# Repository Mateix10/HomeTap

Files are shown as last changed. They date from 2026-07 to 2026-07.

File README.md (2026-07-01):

# HomeTap
A haptic button that connects to HomeAssistant

I always wanted a premium button that is simple and only does a few actions - Toggle the lights on and off and change the color of the LEDs in my room.

# Design
For the design, I used a very simple and minimalistic look, while looking sleek and modern.

It features a LED ring made out of 24 RGB LEDs that light up when the user's finger gets close to the button. This design is inspired from the prototype steam box.

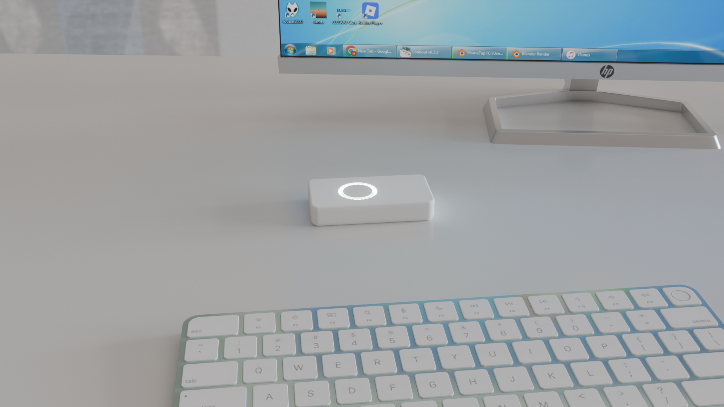
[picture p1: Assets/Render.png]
Render


# Schematic and PCB
This device features a custom pcb. I used [kicad](https://www.kicad.org/).

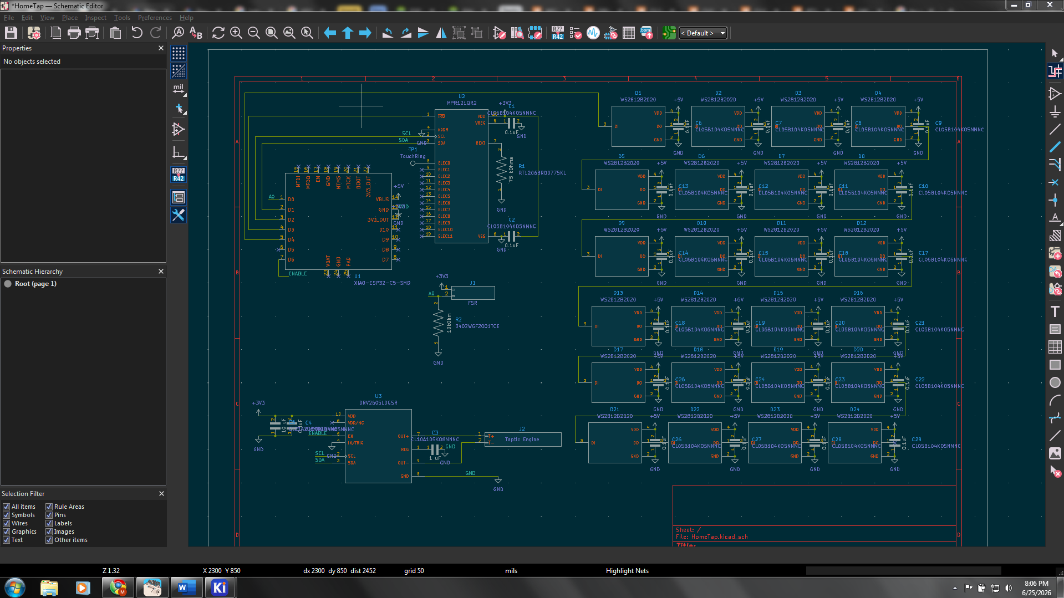
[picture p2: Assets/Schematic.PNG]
Schematic


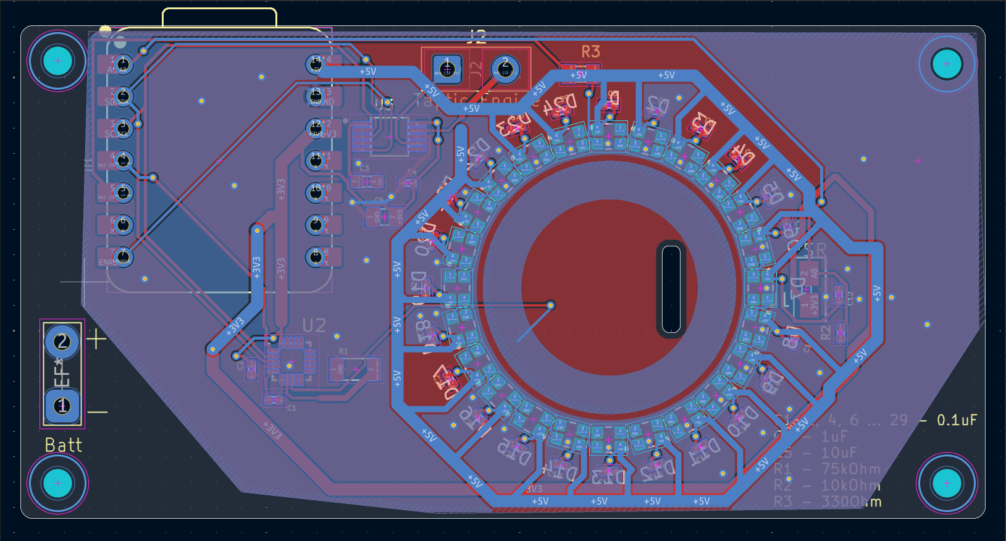
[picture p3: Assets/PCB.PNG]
PCB


# Credits
This project uses:

[KICAD](https://www.kicad.org/)

[Blender](https://www.blender.org/) - For renders

[HackClub Fallout](fallout.hackclub.com) - Founding

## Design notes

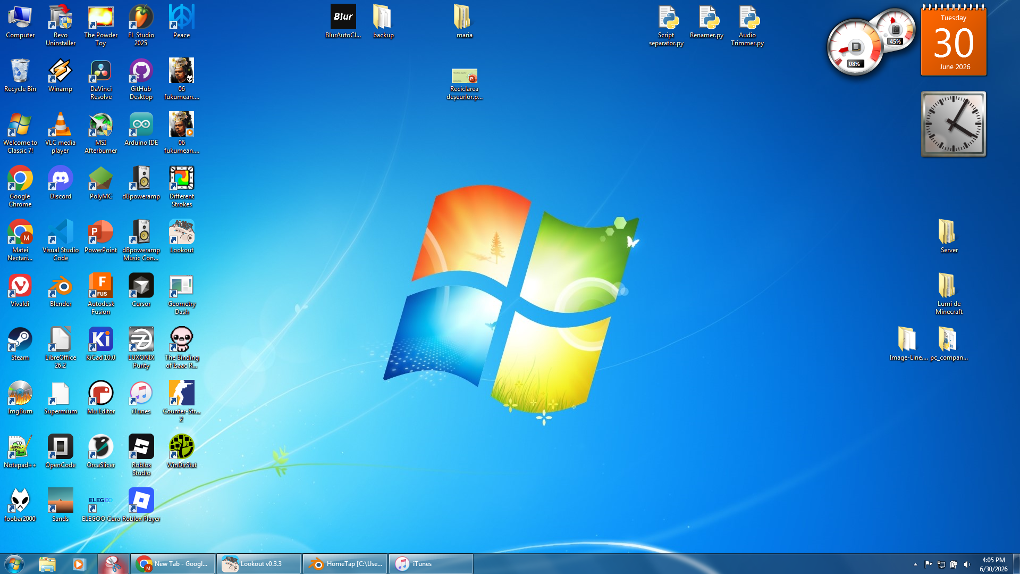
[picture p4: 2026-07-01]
CAD/Blender/assets/models/office-monitor-h_9a68db67-679b-459e-a5c5-594c98094943/Screen.PNG

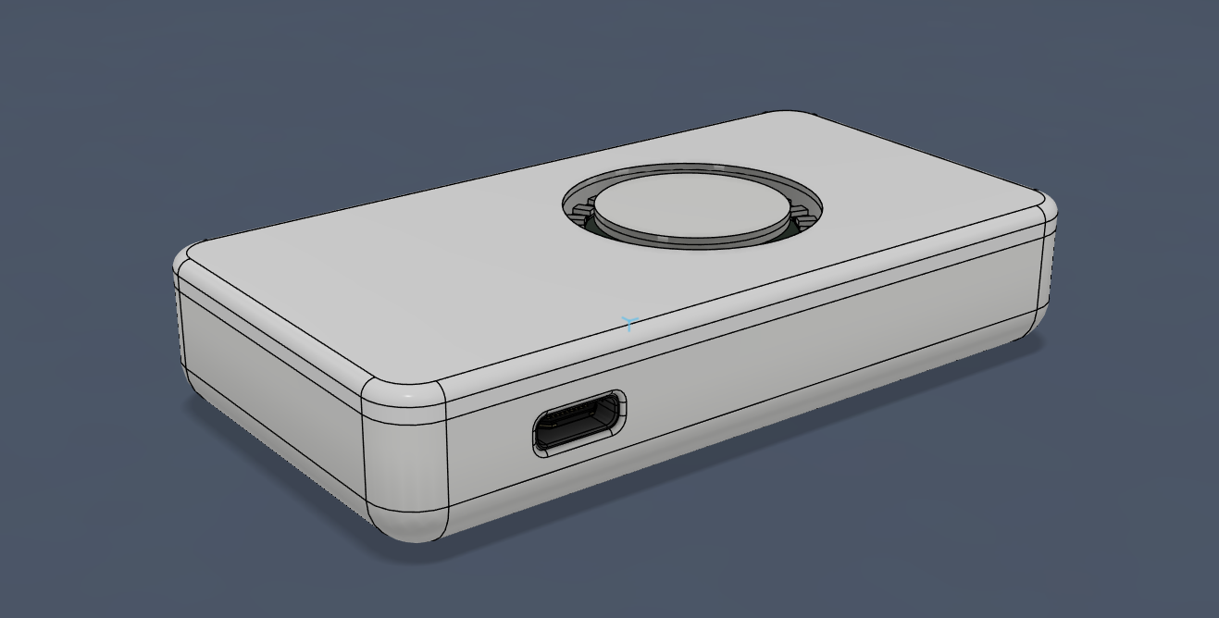
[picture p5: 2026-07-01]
Assets/Enclosure.PNG

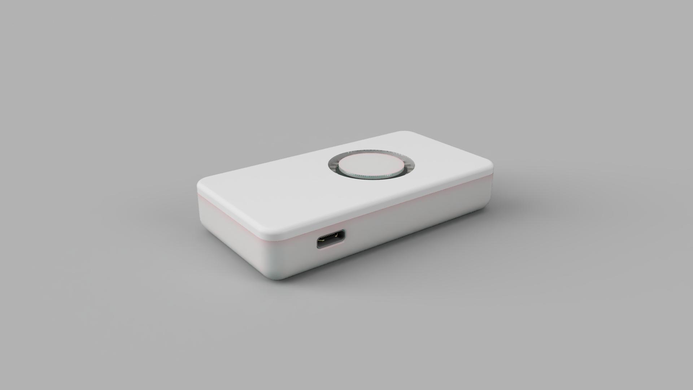
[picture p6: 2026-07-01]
Assets/First_render.jpg

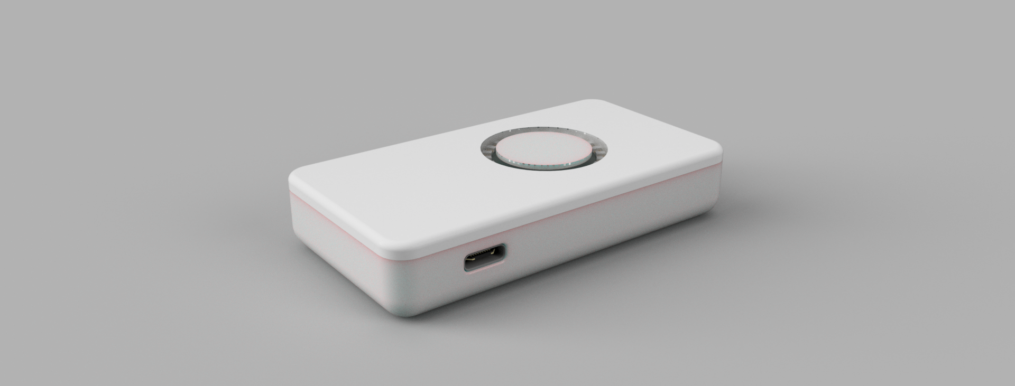
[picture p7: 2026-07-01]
Assets/HomeTap v21.png

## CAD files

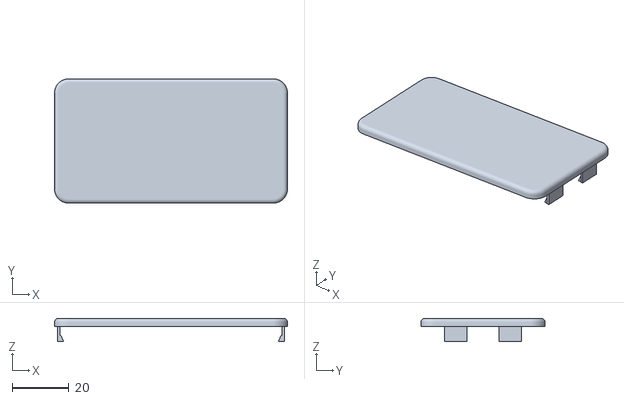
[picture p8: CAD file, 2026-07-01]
CAD/Case_Top_3dPrint.stl
82.3 x 43.9 x 8.30

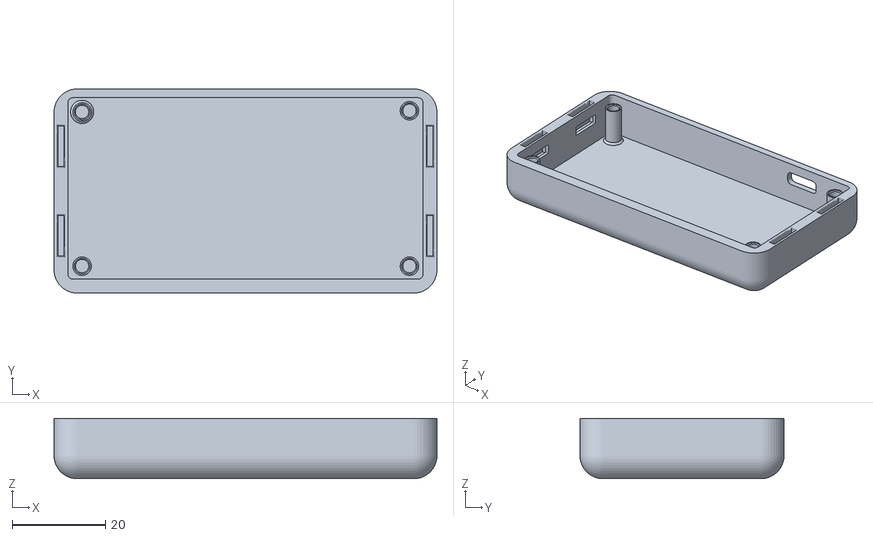
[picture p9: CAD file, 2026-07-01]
CAD/Case_Bottom_3dPrint.stl
82.3 x 43.9 x 13.0

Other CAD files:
CAD/Blender/assets/models/apple-keyboard-w_6d4bd5a8-715a-4650-9c84-7f3591e86bac/apple-keyboard-wireless_2K_df57d479-b608-4e0a-9e4b-379825c70fa6.blend
CAD/Blender/assets/models/apple-wireless-m_81714ff3-cdf1-4f34-aab5-abd4979d42c2/apple-wireless-mouse_2K_a569e3a7-982f-443b-bdad-af356afd9dd6.blend
CAD/Blender/assets/models/office-monitor-h_9a68db67-679b-459e-a5c5-594c98094943/office-monitor-hp-27-inch-black_2K_fdefae49-95da-438c-9247-394331862c4f.blend
CAD/Case_Bottom.f3d
CAD/Case_Top.f3d

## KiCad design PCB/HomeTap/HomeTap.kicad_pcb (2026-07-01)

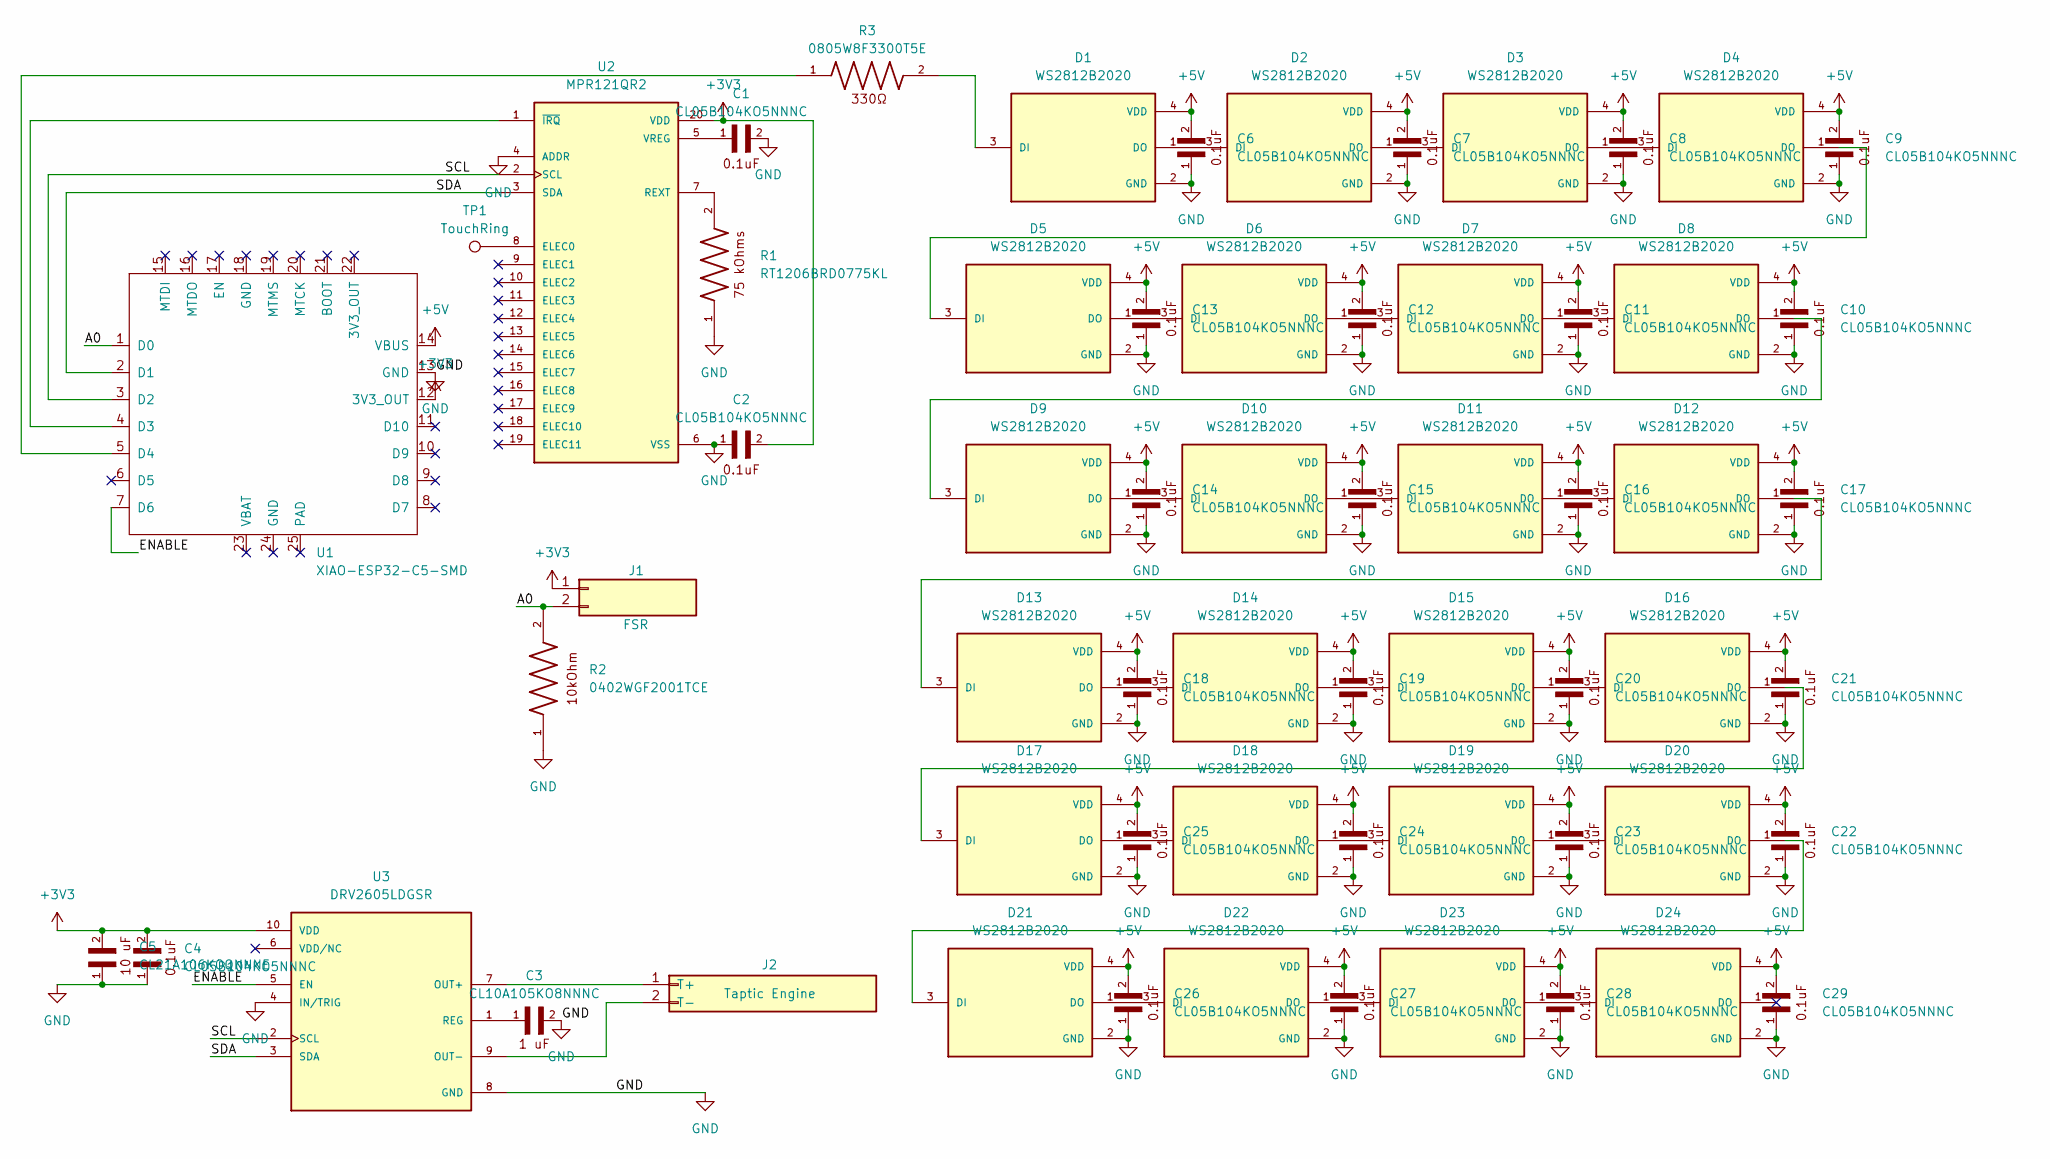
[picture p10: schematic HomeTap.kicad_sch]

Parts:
C1, C2, C4, C6, C7, C8, C9, C10, C11, C12, C13, C14, C15, C16, C17, C18, C19, C20, C21, C22, C23, C24, C25, C26, C27, C28, C29: CL05B104KO5NNNC; CAPC1005X55N; DigiKey_Part_Number 1276-1001-1-ND
C3: CL10A105KO8NNNC; CAPC1608X90N; DigiKey_Part_Number 1276-1034-1-ND
C5: CL21A106KOQNNNE; CAPC2012X140N
D1, D2, D3, D4, D5, D6, D7, D8, D9, D10, D11, D12, D13, D14, D15, D16, D17, D18, D19, D20, D21, D22, D23, D24: WS2812B2020; LED_WS2812B2020; PARTREV V1.0
J1: FSR
J2: Taptic Engine; SolderWire-0.5sqmm_1x02_P4.6mm_D0.9mm_OD2.1mm
R1: RT1206BRD0775KL; RESC3116X65N
R2: 0402WGF2001TCE; RESC1005X40N; PARTREV V3
R3: 0805W8F3300T5E; RESC2012X65N; PARTREV V3
TP1: TouchRing; TestPoint_Pad_D2.0mm
U1: XIAO-ESP32-C5-SMD; XIAO-ESP32-C5-DIP
U2: MPR121QR2; QFN40P300X300X60-20N
U3: DRV2605LDGSR; SOP50P490X110-10N; PARTREV D

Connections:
+3V3: C2.2, C4.2, C5.2, J1.1, U1.12 (3V3_OUT), U2.20 (VDD), U3.10 (VDD)
+5V: C6.2, C7.2, C8.2, C9.2, C10.2, C11.2, C12.2, C13.2, C14.2, C15.2, C16.2, C17.2, C18.2, C19.2, C20.2, C21.2, C22.2, C23.2, C24.2, C25.2, C26.2, C27.2, C28.2, C29.2, D1.4 (VDD), D2.4 (VDD), D3.4 (VDD), D4.4 (VDD), D5.4 (VDD), D6.4 (VDD), D7.4 (VDD), D8.4 (VDD), D9.4 (VDD), D10.4 (VDD), D11.4 (VDD), D12.4 (VDD), D13.4 (VDD), D14.4 (VDD), D15.4 (VDD), D16.4 (VDD), D17.4 (VDD), D18.4 (VDD), D19.4 (VDD), D20.4 (VDD), D21.4 (VDD), D22.4 (VDD), D23.4 (VDD), D24.4 (VDD), U1.14 (VBUS)
/A0: J1.2, R2.2, U1.1 (D0)
/ENABLE: U1.7 (D6), U3.5 (EN)
/SCL: U1.3 (D2), U2.2 (SCL), U3.2 (SCL)
/SDA: U1.2 (D1), U2.3 (SDA), U3.3 (SDA)
GND: C1.2, C2.1, C3.2, C4.1, C5.1, C6.1, C7.1, C8.1, C9.1, C10.1, C11.1, C12.1, C13.1, C14.1, C15.1, C16.1, C17.1, C18.1, C19.1, C20.1, C21.1, C22.1, C23.1, C24.1, C25.1, C26.1, C27.1, C28.1, C29.1, D1.2 (GND), D2.2 (GND), D3.2 (GND), D4.2 (GND), D5.2 (GND), D6.2 (GND), D7.2 (GND), D8.2 (GND), D9.2 (GND), D10.2 (GND), D11.2 (GND), D12.2 (GND), D13.2 (GND), D14.2 (GND), D15.2 (GND), D16.2 (GND), D17.2 (GND), D18.2 (GND), D19.2 (GND), D20.2 (GND), D21.2 (GND), D22.2 (GND), D23.2 (GND), D24.2 (GND), R1.1, R2.1, U1.13 (GND), U2.4 (ADDR), U2.6 (VSS), U3.4 (IN/TRIG), U3.8 (GND)
unnamed: D1.3 (DI), R3.2
unnamed: D1.1 (DO), D2.3 (DI)
unnamed: D2.1 (DO), D3.3 (DI)
unnamed: D3.1 (DO), D4.3 (DI)
unnamed: D4.1 (DO), D5.3 (DI)
unnamed: D5.1 (DO), D6.3 (DI)
unnamed: D6.1 (DO), D7.3 (DI)
unnamed: D7.1 (DO), D8.3 (DI)
unnamed: D8.1 (DO), D9.3 (DI)
unnamed: D9.1 (DO), D10.3 (DI)
unnamed: D10.1 (DO), D11.3 (DI)
unnamed: D11.1 (DO), D12.3 (DI)
unnamed: D12.1 (DO), D13.3 (DI)
unnamed: D13.1 (DO), D14.3 (DI)
unnamed: D14.1 (DO), D15.3 (DI)
unnamed: D15.1 (DO), D16.3 (DI)
unnamed: D16.1 (DO), D17.3 (DI)
unnamed: D17.1 (DO), D18.3 (DI)
unnamed: D18.1 (DO), D19.3 (DI)
unnamed: D19.1 (DO), D20.3 (DI)
unnamed: D20.1 (DO), D21.3 (DI)
unnamed: D21.1 (DO), D22.3 (DI)
unnamed: D22.1 (DO), D23.3 (DI)
unnamed: D23.1 (DO), D24.3 (DI)
unnamed: J2.1 (T+), U3.7 (OUT+)
unnamed: J2.2 (T-), U3.9 (OUT-)
unnamed: U1.4 (D3), U2.1 (~IRQ)
unnamed: R3.1, U1.5 (D4)
unnamed: TP1.1, U2.8 (ELEC0)
unnamed: R1.2, U2.7 (REXT)
unnamed: C1.1, U2.5 (VREG)
unnamed: C3.1, U3.1 (REG)

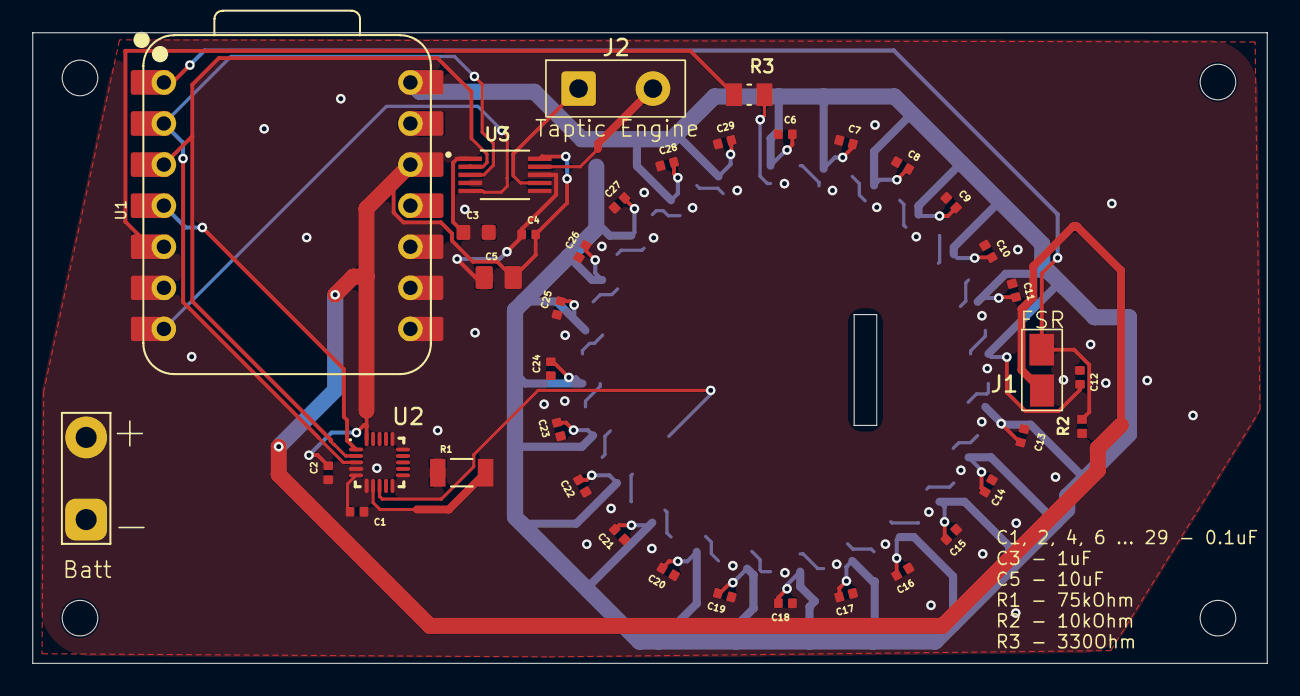
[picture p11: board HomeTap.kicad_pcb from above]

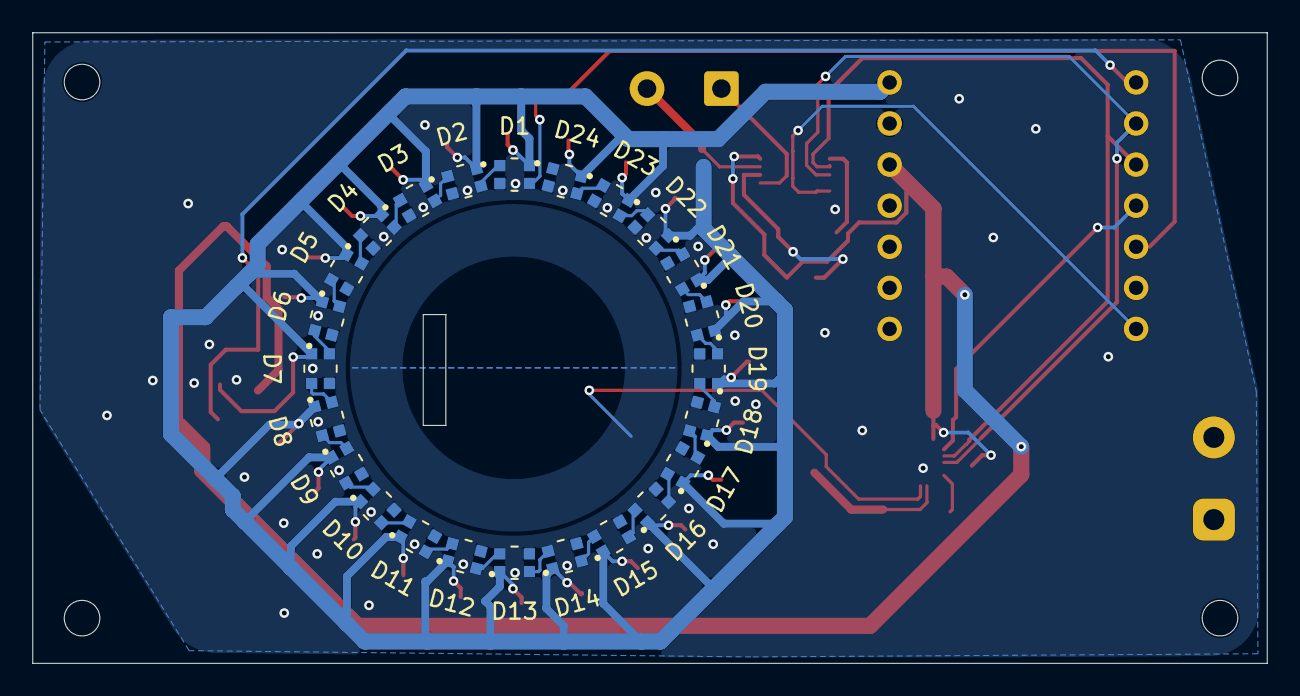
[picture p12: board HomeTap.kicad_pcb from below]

Board: 2 copper layers, 76.3 x 39.0 mm, 62 parts (24 on the bottom side), 38 nets.

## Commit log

2026-07-01 Update README
    Expanded the README to include design details, schematic, PCB information, and credits for tools used.
2026-07-01 Add CAD Files
    [Case_Bottom.f3d, Case_Bottom_3dPrint.stl, Case_Top.f3d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]
2026-07-01 Add Gerber
    [HomeTap-B_Cu.gbl, HomeTap-B_Mask.gbs, HomeTap-B_Paste.gbp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]
